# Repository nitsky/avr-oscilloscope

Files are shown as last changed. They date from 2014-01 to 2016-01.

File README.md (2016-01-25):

# avr-oscilloscope

Pushing the ATMega328 to its limit: A 150 ksps oscilloscope with edge triggering written in AVR C.

## ADC
The ADC is configured to operate in free running mode, which means it samples continuously and calls an interrupt when each new sample is ready, which is once every 13.5 ADC clock cycles. The top ADC clock speed for 8-bit resolution is 4MHz, a prescaler of 4 with a 16MHz processor clock. Here is the code that configures the ADC and then functions to start and stop it.

```c
void init_adc()
{
    cbi(ADCSRA, ADEN); // disable adc
    cbi(ADCSRA, ADSC); // stop conversion

    cbi(ADMUX, REFS1); // choose AVcc with external cap
    sbi(ADMUX, REFS0); // for adc voltage reference
    sbi(ADMUX, ADLAR); // left adjust adc readings for 8 bit
    ADMUX |= ( 0 & 0x07 ); // choose analog 0 pin

    sbi(ADCSRA, ADATE); // enable auto trigger of adc
    sbi(ADCSRA, ADIE); // enable adc interrupt

    cbi(ADCSRA, ADPS2); // set prescaler to 4
    sbi(ADCSRA, ADPS1); //
    cbi(ADCSRA, ADPS0); //

    cbi(ADCSRB, ACME); // choose AIN1 for comparator

    cbi(ADCSRB, ADTS2); // choose free running mode
    cbi(ADCSRB, ADTS1); // for auto trigger adc
    cbi(ADCSRB, ADTS0);
}

void start_adc()
{
    sbi( ADCSRA, ADEN );
    sbi( ADCSRA, ADSC );
}

void stop_adc()
{
    cbi( ADCSRA, ADEN );
    cbi( ADCSRA, ADSC );
}
```

## Comparator

The comparator is configured without an interrupt because the comparator's value is read in the ADC interrupt.

```c
void init_comparator(void)
{
    cbi( ACSR, ACD ); // turn on comparator
    cbi( ACSR, ACBG ); // choose digital pin 7 for comparator
    cbi( ACSR, ACIE ); // disable interrupt

    cbi( ACSR, ACIC ); // disable input capture interrupt
}
```

## ADC Interrupt

The ADC interrupt implements a circular buffer of 1024 8-bit samples. At each interrupt it checks if the comparator has detected the input voltage above the trigger level eight consecutive times, a simple noise filter, then sets the stop_index which the interrupt will freeze itself at when it hits it, which is the current index plus half the buffer length, so that the trigger event is always at the center of the circular buffer.

```c
ISR(ADC_vect)
{
    adc_data[adc_counter] = ADCH; // read adc
    if (freeze) {
        freeze = false;
        stop_index = -1;
    } else if (adc_counter == stop_index) {
        freeze = true;
    } else if ( comp == 0 && (ACSR & (1 << ACO)) && stop_index < 0) {
        stop_index = ((adc_counter + (ADC_BUFFER_SIZE >> 1) ) & 0x03FF);
    }
    adc_counter = (( adc_counter + 1 ) & 0x03FF); // increment adc counter
    comp = (comp << 1); // push next comparator value
    comp += (ACSR & (1 << ACO));
}
```

## Trigger Level DAC

The ATMega328 does not have a DAC built-in to set the trigger level, but you can cheat by using PWM with a low-pass filter. For PWM frequency 490 Hz, I used a 100 kΩ resistor and 1 uF capacitor you can get reasonable delay and ripple in the mV range. Below is the code to use PWM on PD3. After this setup function the duty cycle can be changed by modifying the OCR2B register.

```c
void init_pwm()
{
    setOutput(DDRD, PORTD3);
    sbi(TCCR2A, COM2B1);
    sbi(TCCR2A, WGM20);
    sbi(TCCR2B, CS22);
    OCR2B = 128;
}
```

## UART

The UART is configured for 115200 baud. Here's the code to initialize it and then functions to send and receive characters.

```
#define BAUD 115200
#include <util/setbaud.h>

void uart_init() {
    UBRR0H = UBRRH_VALUE;
    UBRR0L = UBRRL_VALUE;

#if USE_2X
    UCSR0A |= _BV(U2X0);
#else
    UCSR0A &= ~(_BV(U2X0));
#endif

    UCSR0C = _BV(UCSZ01) | _BV(UCSZ00); // 8 bit
    UCSR0B = _BV(RXEN0) | _BV(TXEN0); // enable rx and tx
}

void uart_putchar(char c) {
    loop_until_bit_is_set(UCSR0A, UDRE0); // wait until reg empty
    UDR0 = c;
}

char uart_getchar() {
    loop_until_bit_is_set(UCSR0A, RXC0); // wait for byte
    return UDR0;
}
```

## Signal Conditioning

Below is the input signal conditioning circuit. The ADC operates from 0V to 5V, so the circuit uses an op-amp to scale and offset an incoming signal from -10V to 10V to 0V to 5V. It does this with a divide by four voltage divider and then a voltage adder with a 2.5V input from a voltage divider. All resistors in the schematic are 10kΩ except for R11 with is 1 MΩ to make the scope appear as a high impedence to whatever circuit it is measuring.

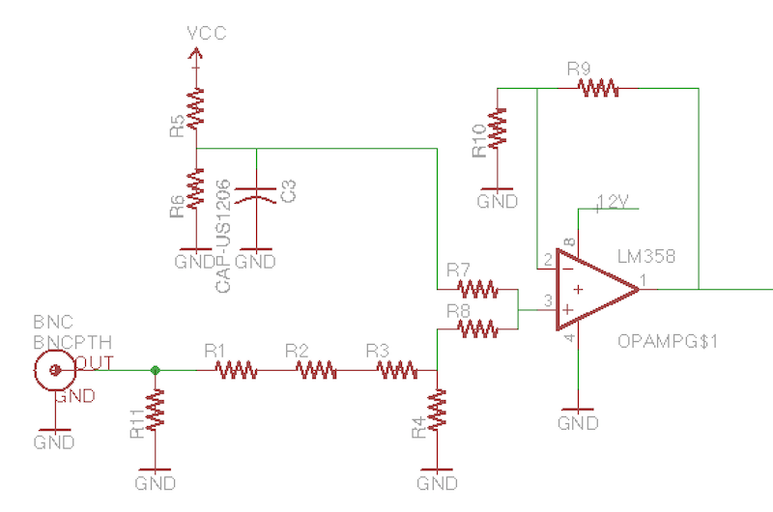
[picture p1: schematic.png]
circuit diagram


## Results

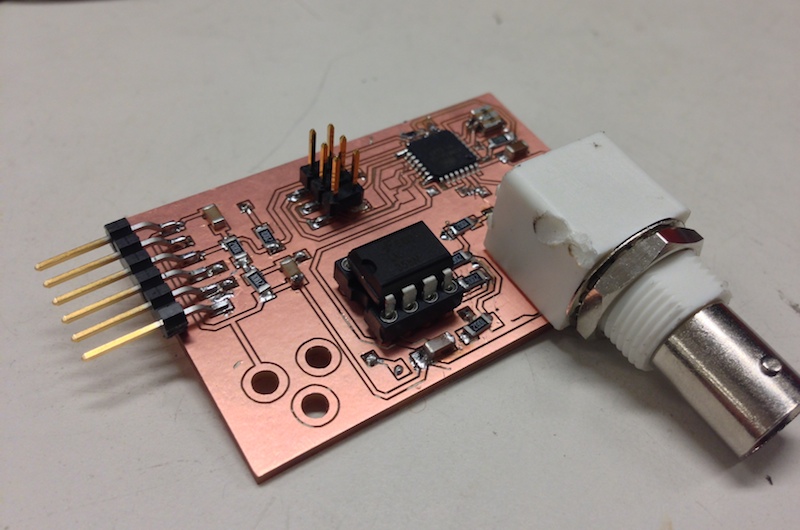
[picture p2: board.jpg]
circuit board


[Watch Video](https://vimeo.com/80199995)

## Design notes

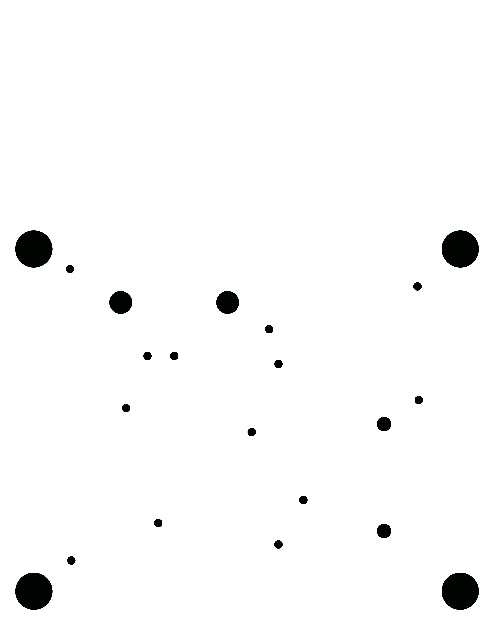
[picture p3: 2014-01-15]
fab_files/holes.png

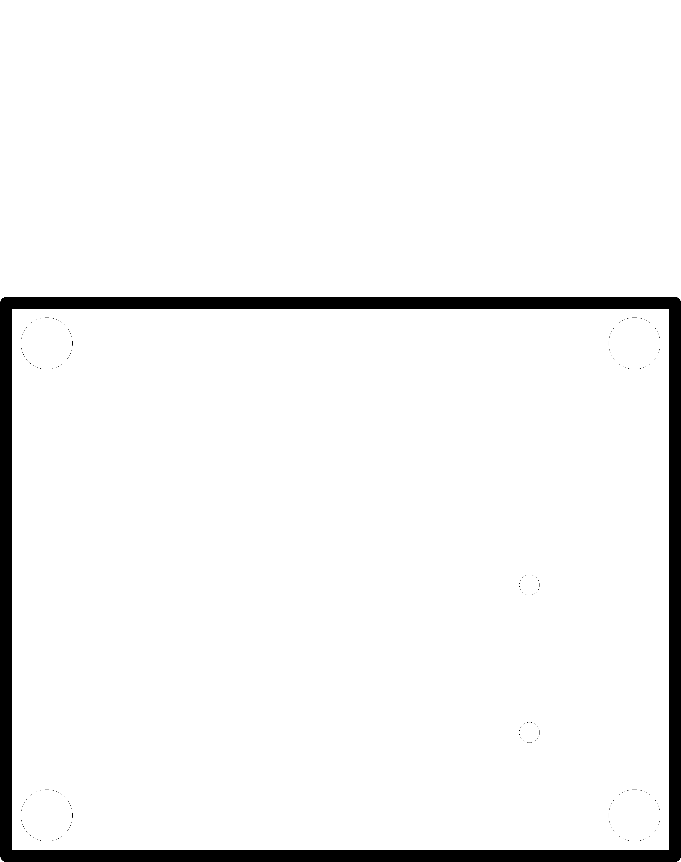
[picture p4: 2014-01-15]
fab_files/cutout.png

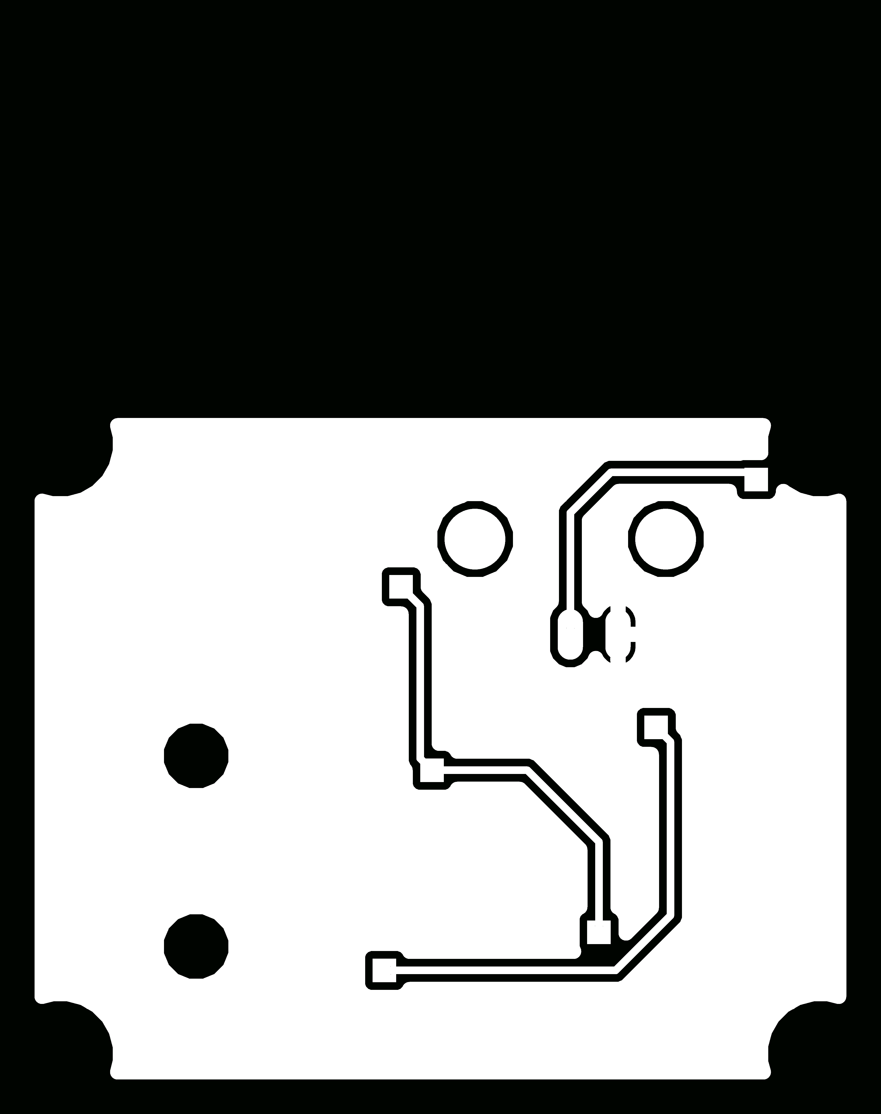
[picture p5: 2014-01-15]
fab_files/bottom.png

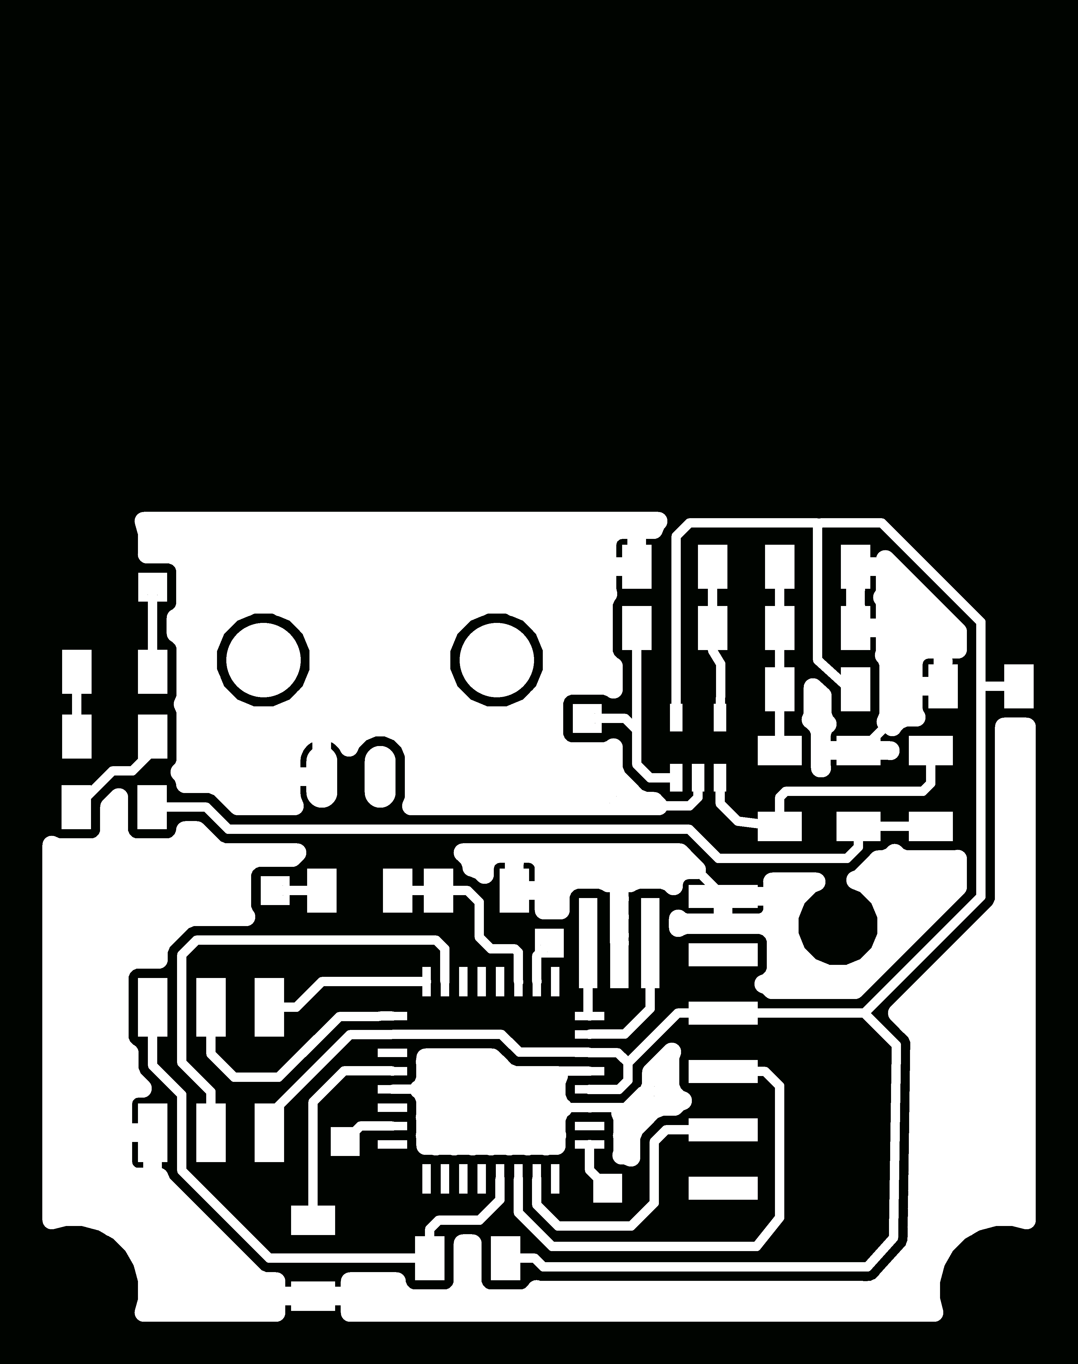
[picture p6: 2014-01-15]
fab_files/top.png

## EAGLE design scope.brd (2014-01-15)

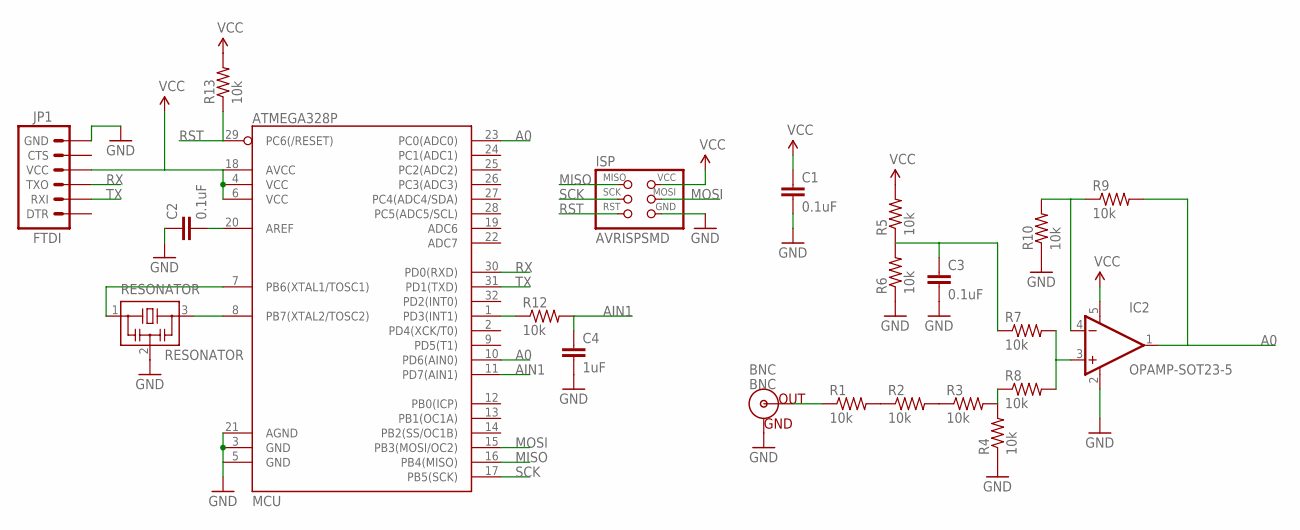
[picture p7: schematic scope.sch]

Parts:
BNC: BNC
C1, C2, C3: 0.1uF; C1206FAB
C4: 1uF; C1206FAB
IC2: OPAMP-SOT23-5; SOT23-5
ISP: AVRISPSMD; 2X3SMD
JP1: FTDI; FTDI-SMD
MCU: ATMEGA328P; TQFP32-08
R1, R2, R3, R4, R5, R6, R7, R8, R9, R10, R12, R13: 10k; R1206FAB
RESONATOR: RESONATOR; EFOBM

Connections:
A0: IC2.1 (OUT), MCU.10 (PD6(AIN0)), MCU.23 (PC0(ADC0)), R9.2
AIN1: C4.1, MCU.11 (PD7(AIN1)), R12.2
GND: BNC.GND, C1.2, C2.1, C3.2, C4.2, IC2.2 (V-), ISP.6 (GND), JP1.6 (GND), MCU.3 (GND), MCU.5 (GND), MCU.21 (AGND), R4.1, R6.1, R10.1, RESONATOR.2
MISO: ISP.1 (MISO), MCU.16 (PB4(MISO))
MOSI: ISP.4 (MOSI), MCU.15 (PB3(MOSI/OC2))
unnamed: MCU.7 (PB6(XTAL1/TOSC1)), RESONATOR.1
unnamed: MCU.8 (PB7(XTAL2/TOSC2)), RESONATOR.3
unnamed: BNC.S (OUT), R1.1
unnamed: C2.2, MCU.20 (AREF)
unnamed: R1.2, R2.1
unnamed: R2.2, R3.1
unnamed: R3.2, R4.2, R8.1
unnamed: C3.1, R5.1, R6.2, R7.1
unnamed: IC2.3 (+IN), R7.2, R8.2
unnamed: IC2.4 (-IN), R9.1, R10.2
unnamed: MCU.1 (PD3(INT1)), R12.1
RST: ISP.5 (RST), MCU.29 (PC6(/RESET)), R13.1
RX: JP1.3 (TXO), MCU.30 (PD0(RXD))
SCK: ISP.3 (SCK), MCU.17 (PB5(SCK))
TX: JP1.2 (RXI), MCU.31 (PD1(TXD))
VCC: C1.1, IC2.5 (V+), ISP.2 (VCC), JP1.4 (VCC), MCU.4 (VCC), MCU.6 (VCC), MCU.18 (AVCC), R5.2, R13.2

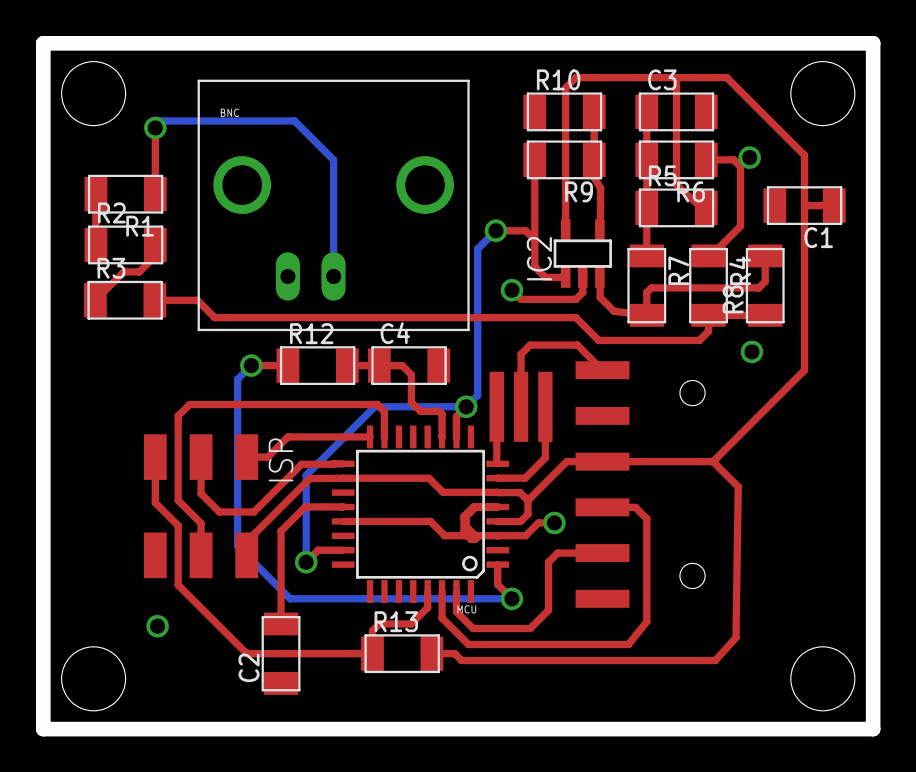
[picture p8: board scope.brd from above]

Board: 2 copper layers, 46.1 x 38.1 mm, 22 parts (0 on the bottom side), 21 nets.

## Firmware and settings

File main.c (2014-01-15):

#include <avr/io.h>
#include <avr/interrupt.h>
#include <stdint.h>
#include <stdbool.h>

#define BAUD 115200
#include <util/setbaud.h>

#define sbi(REG,BIT) (REG |= (1 << BIT))
#define cbi(REG,BIT) (REG &= ~(1 << BIT))

#define setOutput(ddr, pin) ((ddr) |= (1 << (pin)))
#define setLow(port, pin) ((port) &= ~(1 << (pin)))
#define setHigh(port, pin) ((port) |= (1 << (pin)))
#define pulse(port, pin) do { setHigh((port), (pin)); setLow((port), (pin)); } while (0)
#define outputState(port, pin) ((port) & (1 << (pin)))

#define ADC_BUFFER_SIZE 1024

volatile uint16_t adc_counter;
volatile uint8_t adc_data[ADC_BUFFER_SIZE];

volatile int16_t stop_index = -1;
volatile bool freeze = false;
volatile uint16_t timer = 0;
volatile uint8_t comp = 0xFF;

void init_adc();
void init_comparator();
void start_adc();
void stop_adc();

void init_adc()
{
    cbi(ADCSRA, ADEN); // disable adc
    cbi(ADCSRA, ADSC); // stop conversion

    cbi(ADMUX, REFS1); // choose AVcc with external cap
    sbi(ADMUX, REFS0); // for adc voltage reference
    sbi(ADMUX, ADLAR); // left adjust adc readings for 8 bit
    ADMUX |= ( 0 & 0x07 ); // choose analog 0 pin

    sbi(ADCSRA, ADATE); // enable auto trigger of adc
    sbi(ADCSRA, ADIE); // enable adc interrupt

    cbi(ADCSRA, ADPS2); // set prescaler to 4
    sbi(ADCSRA, ADPS1); //
    cbi(ADCSRA, ADPS0); //

    cbi(ADCSRB, ACME); // choose AIN1 for comparator

    cbi(ADCSRB, ADTS2); // choose free running mode
    cbi(ADCSRB, ADTS1); // for auto trigger adc
    cbi(ADCSRB, ADTS0);
}

void start_adc()
{
    sbi( ADCSRA, ADEN );
    sbi( ADCSRA, ADSC );
}

void stop_adc()
{
    cbi( ADCSRA, ADEN );
    cbi( ADCSRA, ADSC );
}

void init_comparator(void)
{
    cbi( ACSR, ACD ); // turn on comparator
    cbi( ACSR, ACBG ); // choose digital pin 7 for comparator
    cbi( ACSR, ACIE ); // disable interrupt

    cbi( ACSR, ACIC ); // disable input capture interrupt
}

ISR(ADC_vect)
{
    adc_data[adc_counter] = ADCH; // read adc
    if (freeze) {
        freeze = false;
        stop_index = -1;
    } else if (adc_counter == stop_index) {
        freeze = true;
    } else if ( comp == 0 && (ACSR & (1 << ACO)) && stop_index < 0) {
        stop_index = ((adc_counter + (ADC_BUFFER_SIZE >> 1) ) & 0x03FF);
    }
    adc_counter = (( adc_counter + 1 ) & 0x03FF); // increment adc counter
    timer = timer + 1;
    comp = (comp << 1); // push next comparator value
    comp += (ACSR & (1 << ACO));
}

void uart_init() {
    UBRR0H = UBRRH_VALUE;
    UBRR0L = UBRRL_VALUE;

#if USE_2X
    UCSR0A |= _BV(U2X0);
#else
    UCSR0A &= ~(_BV(U2X0));
#endif

    UCSR0C = _BV(UCSZ01) | _BV(UCSZ00); // 8 bit
    UCSR0B = _BV(RXEN0) | _BV(TXEN0); // enable rx and tx
}

void uart_putchar(char c) {
    loop_until_bit_is_set(UCSR0A, UDRE0); // wait until reg empty
    UDR0 = c;
}

char uart_getchar() {
    loop_until_bit_is_set(UCSR0A, RXC0); // wait for byte
    return UDR0;
}

void init_pwm()
{
    setOutput(DDRD, PORTD3);
    sbi(TCCR2A, COM2B1);
    sbi(TCCR2A, WGM20);
    sbi(TCCR2B, CS22);
    OCR2B = 128;
}

void read_cmd()
{
    timer = 0;
    while (!(freeze || timer > 1023)); // wait for the adc to freeze
    stop_adc();

    int i;
    for (i = 0; i < ADC_BUFFER_SIZE - adc_counter; i++)
        uart_putchar(((char *)adc_data)[adc_counter + i]);
    for (i = 0; i < adc_counter; i++)
        uart_putchar(((char *)adc_data)[i]);

    start_adc();
}

void trigger_val_cmd()
{
    uint8_t val = 0;
    val += ((uart_getchar() - 48) * 100);
    val += ((uart_getchar() - 48) * 10);
    val += ((uart_getchar() - 48) * 1);
    OCR2B = val;
}

int main() {

    uart_init();

    sei(); // enable interrupts

    init_adc();
    init_comparator();
    init_pwm();

    start_adc();

    while (true) {

        char command = uart_getchar();

        switch (command) {
            case 'p':
                uart_putchar('p');
                break;
            case 'r':
                read_cmd();
                break;
            case 't':
                trigger_val_cmd();
                break;
        }

    }

    return 0;

}

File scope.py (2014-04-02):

import os
import sys
import wx

import serial
from serial.tools import list_ports
import struct

import matplotlib
matplotlib.use('WXAgg')
from matplotlib.figure import Figure
from matplotlib.backends.backend_wxagg import FigureCanvasWxAgg as FigCanvas
import numpy as np

class GraphFrame(wx.Frame):

    title = "FabScope"

    def __init__(self):
        wx.Frame.__init__(self, None, -1, self.title)

        self.port = serial.Serial('/dev/tty.usbserial-FTGO08I9', 115200)

        self.data = [0]*1024
        self.paused = False

        self.create_menu()
        self.create_status_bar()
        self.create_main_panel()

        self.redraw_timer = wx.Timer(self)
        self.Bind(wx.EVT_TIMER, self.on_redraw_timer, self.redraw_timer)
        self.redraw_timer.Start(100)

    def create_menu(self):
        self.menubar = wx.MenuBar()

        menu_file = wx.Menu()
        m_exit = menu_file.Append(-1, "E&xit\tCtrl-X", "Exit")
        self.Bind(wx.EVT_MENU, self.on_exit, m_exit)

        self.menubar.Append(menu_file, "&File")
        self.SetMenuBar(self.menubar)

    def create_main_panel(self):
        self.panel = wx.Panel(self)

        self.init_plot()
        self.canvas = FigCanvas(self.panel, -1, self.fig)

        self.container = wx.BoxSizer(wx.VERTICAL)
        self.container.Add(self.canvas, 1, flag=wx.LEFT | wx.TOP | wx.GROW)
        self.panel.SetSizer(self.container)
        self.container.Fit(self)

    def create_status_bar(self):
        self.statusbar = self.CreateStatusBar()

    def init_plot(self):
        self.dpi = 100
        self.fig = Figure((3.0, 3.0), dpi=self.dpi)

        self.axes = self.fig.add_subplot(111)
        self.axes.set_axis_bgcolor('black')

        self.plot_data = self.axes.plot(self.data, linewidth=1, color=(1, 1, 0))[0]

    def draw_plot(self):

        self.axes.set_xbound(lower=0, upper=1023)
        self.axes.set_ybound(lower=-11.0, upper=11.0)

        self.axes.grid(True, color='gray')

        self.plot_data.set_xdata(np.arange(len(self.data)))
        self.plot_data.set_ydata(np.array(self.data))

        self.canvas.draw()

    def on_redraw_timer(self, event):
        self.port.write('r')
        raw = self.port.read(1024)
        print raw
        self.data = list(struct.unpack('B'*1024, raw))
        self.data = [(float(x)/255.0 - 0.5) * 20 for x in self.data]
        self.draw_plot()

    def on_exit(self, event):
        self.Destroy()

    def flash_status_message(self, msg, flash_len_ms=1500):
        self.statusbar.SetStatusText(msg)
        self.timeroff = wx.Timer(self)
        self.Bind(
            wx.EVT_TIMER,
            self.on_flash_status_off,
            self.timeroff)
        self.timeroff.Start(flash_len_ms, oneShot=True)

    def on_flash_status_off(self, event):
        self.statusbar.SetStatusText('')

if __name__ == '__main__':
    app = wx.App()
    app.frame = GraphFrame()
    app.frame.Show()
    app.MainLoop()

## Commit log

2013-11-24 initial import
    [scope.brd, scope.sch]
2014-01-15 modified board and makefile
    [fabscope.brd, fabscope.sch]
2014-01-15 removed old file
    [scope.brd, scope.sch]
2014-01-15 fixes and fuses

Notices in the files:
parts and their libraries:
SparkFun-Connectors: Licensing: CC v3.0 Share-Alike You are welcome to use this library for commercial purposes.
